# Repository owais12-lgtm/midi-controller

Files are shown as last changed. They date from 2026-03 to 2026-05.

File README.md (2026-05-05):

# midi-controller
A MIDI keyboard is basically just a controller. You can use it to trigger notes on a synth or plugin, you can assign the encoder to volume, LFO rate or anything else. So if you don't connect it to anything you won't get any sound.

tldr: its a smaller more weirder keyboard that can help you make music!

# features
- 6 rotary knobs for menu/Midi control
- 4 sliders
- 25 macro keys
- rp2040 based micro controller 
- choc switches
# Images

Screenshot from 2026-03-26 12-45-57
Screenshot from 2026-03-26 12-45-47
Screenshot from 2026-03-26 12-45-36

# CAD
Screenshot from 2026-03-26 12-46-45
Screenshot from 2026-03-26 12-46-54

https://www.tinkercad.com/things/4G5PN0rRYm5-midi-controller-v2

# BOM
| Name | Purpose | Quantity | Total Cost (USD) | Link | Distributor |
|---|---|---|---|---|---|
| switch | switch | 30 | $10.00 | [stackskb.com](https://stackskb.com/store/ttc-low-profile-brown-switches-tactile/) | stacks |
| rpi pico | mcu | 1 | $7.00 | [robu](https://www.google.com/search?client=firefox-b-d&q=rpi+pico+robu) | robu |
| pcb | pcb | 1 | $30.00 | [lioncircuits.com](https://www.lioncircuits.com/quote) | lion pcb |

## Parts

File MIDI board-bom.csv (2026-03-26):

Name | Purpose | Quantity | Total Cost (USD) | Link | Distributor
switch | switch | 30 | 10.00 | https://stackskb.com/store/ttc-low-profile-brown-switches-tactile/ | stacks
rpi pico | mcu | 1 | 7.00 | https://www.google.com/search?client=firefox-b-d&q=rpi+pico+robu | robu
pcb | pcb | 1 | 30.00 | https://www.lioncircuits.com/quote | lion pcb

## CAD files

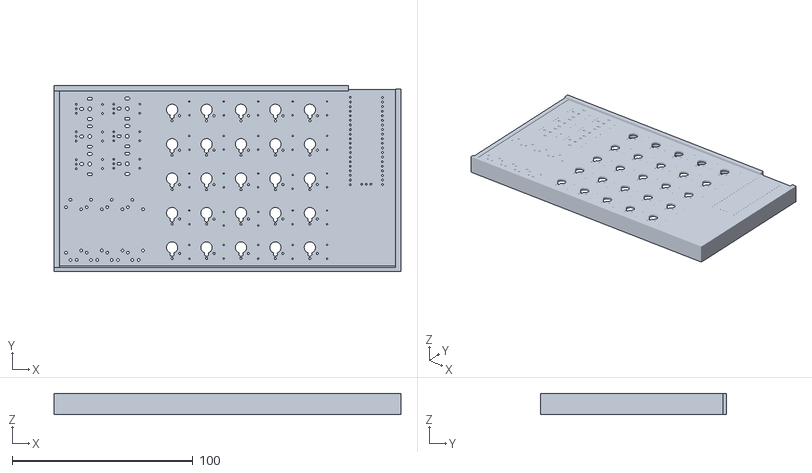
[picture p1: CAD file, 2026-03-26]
CAD/MIDI controller v2.stl
192.0 x 103.0 x 11.8

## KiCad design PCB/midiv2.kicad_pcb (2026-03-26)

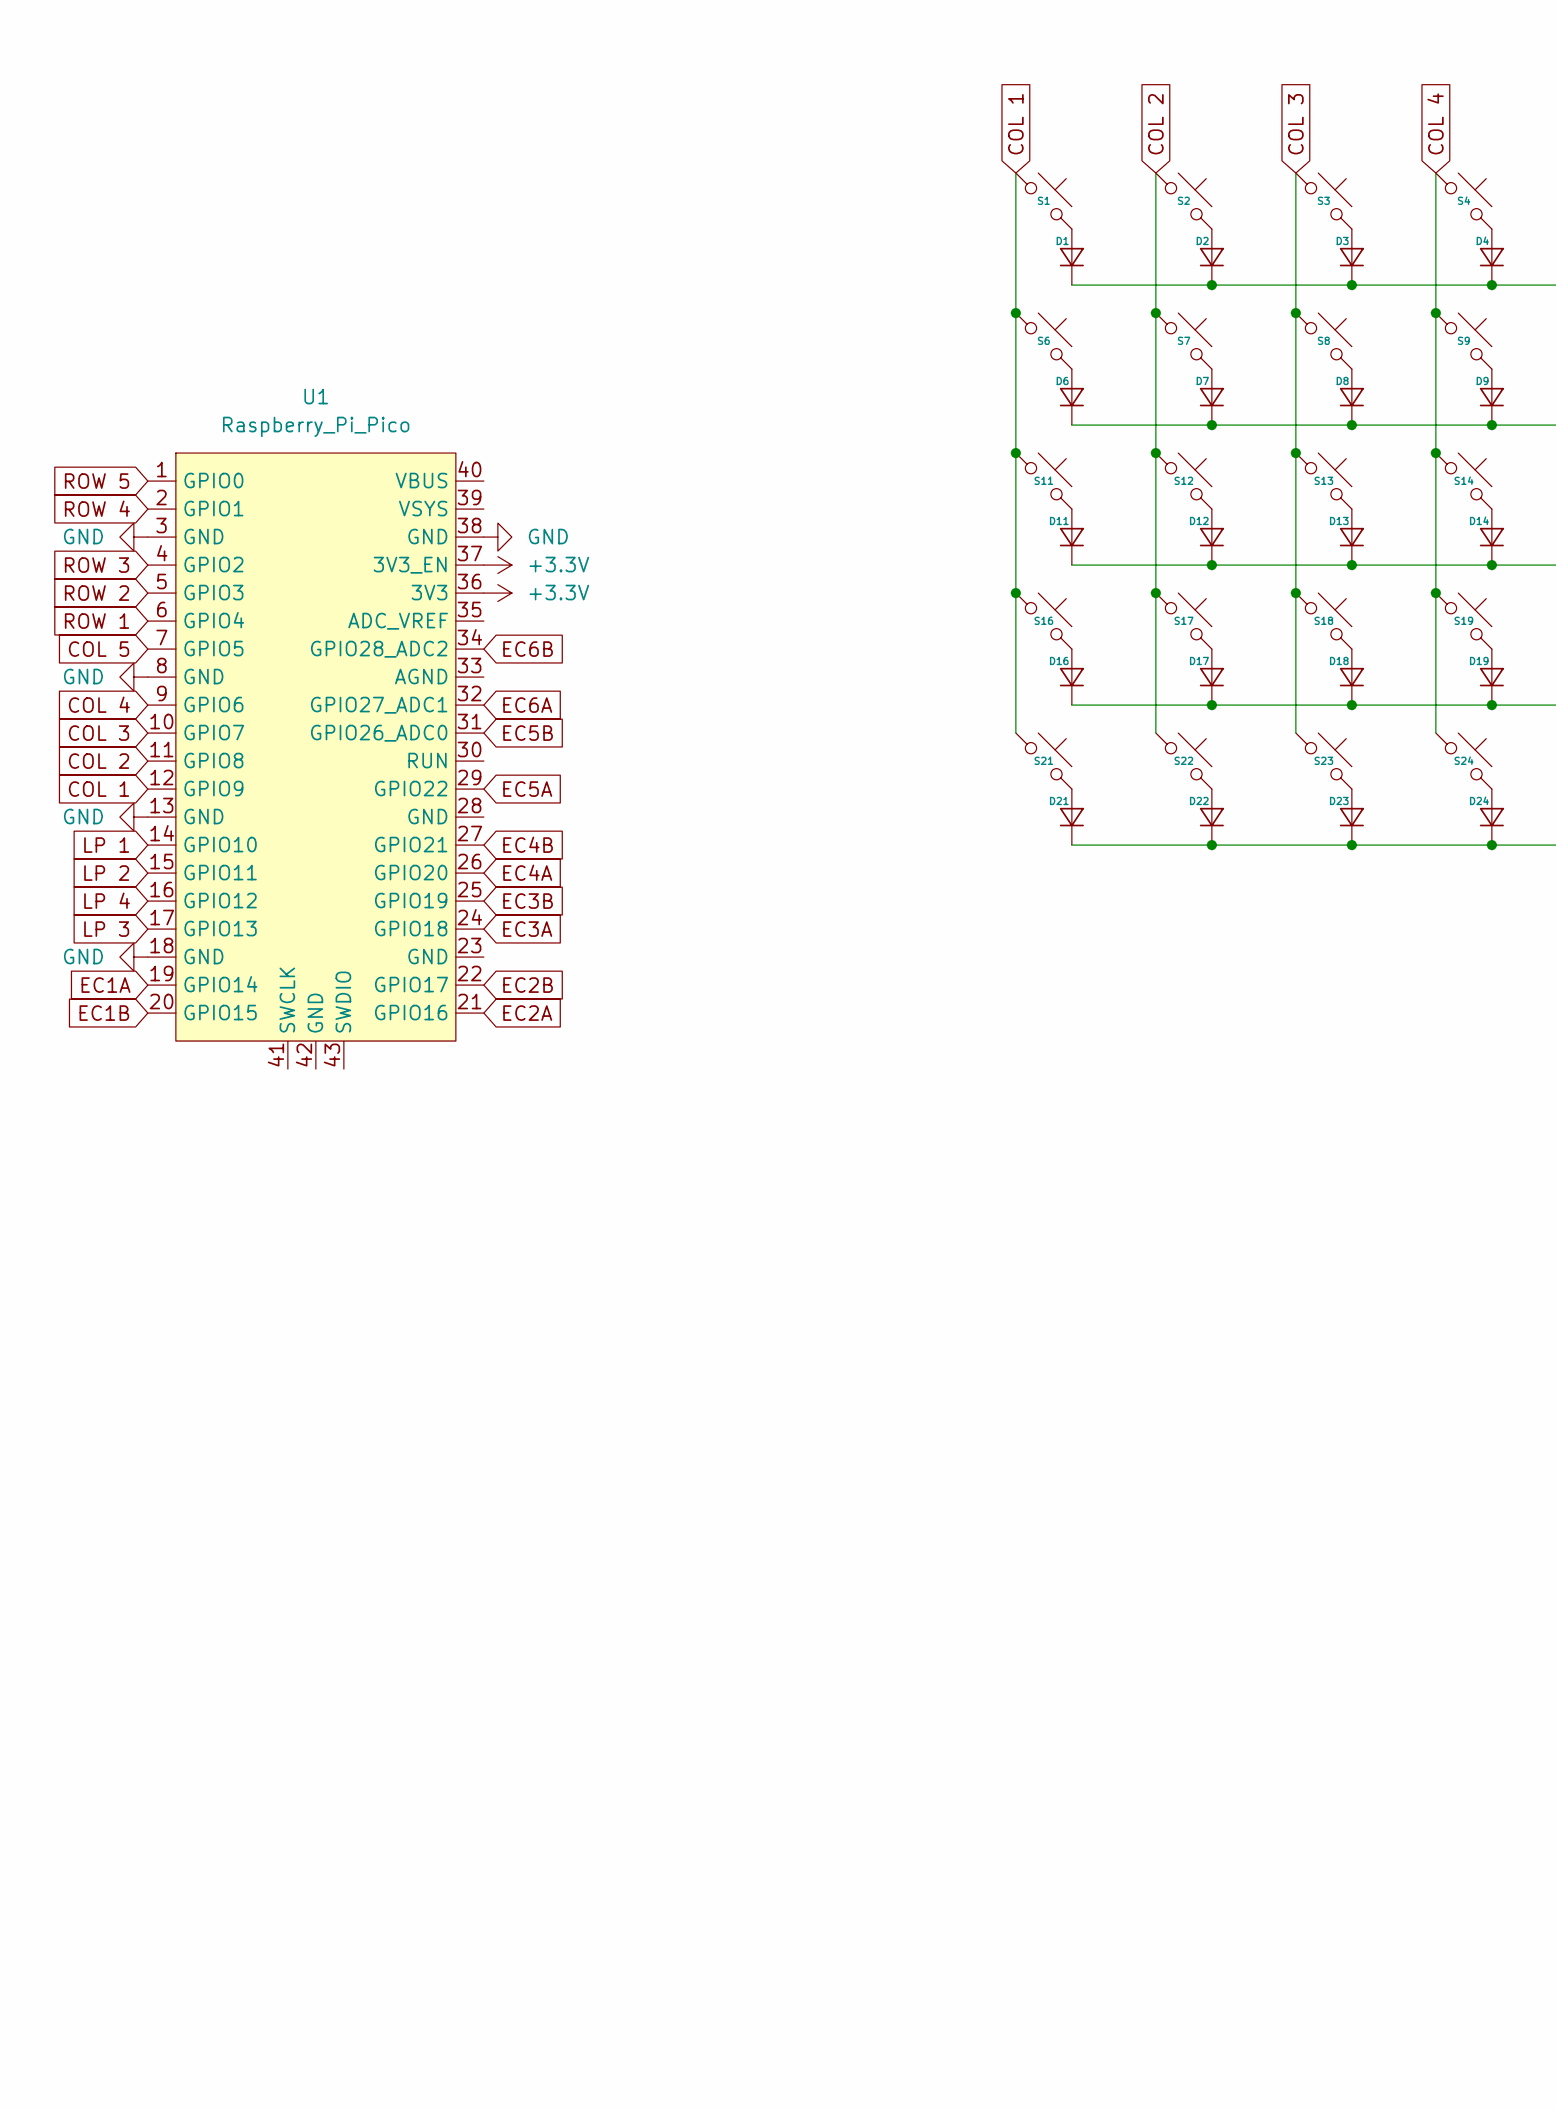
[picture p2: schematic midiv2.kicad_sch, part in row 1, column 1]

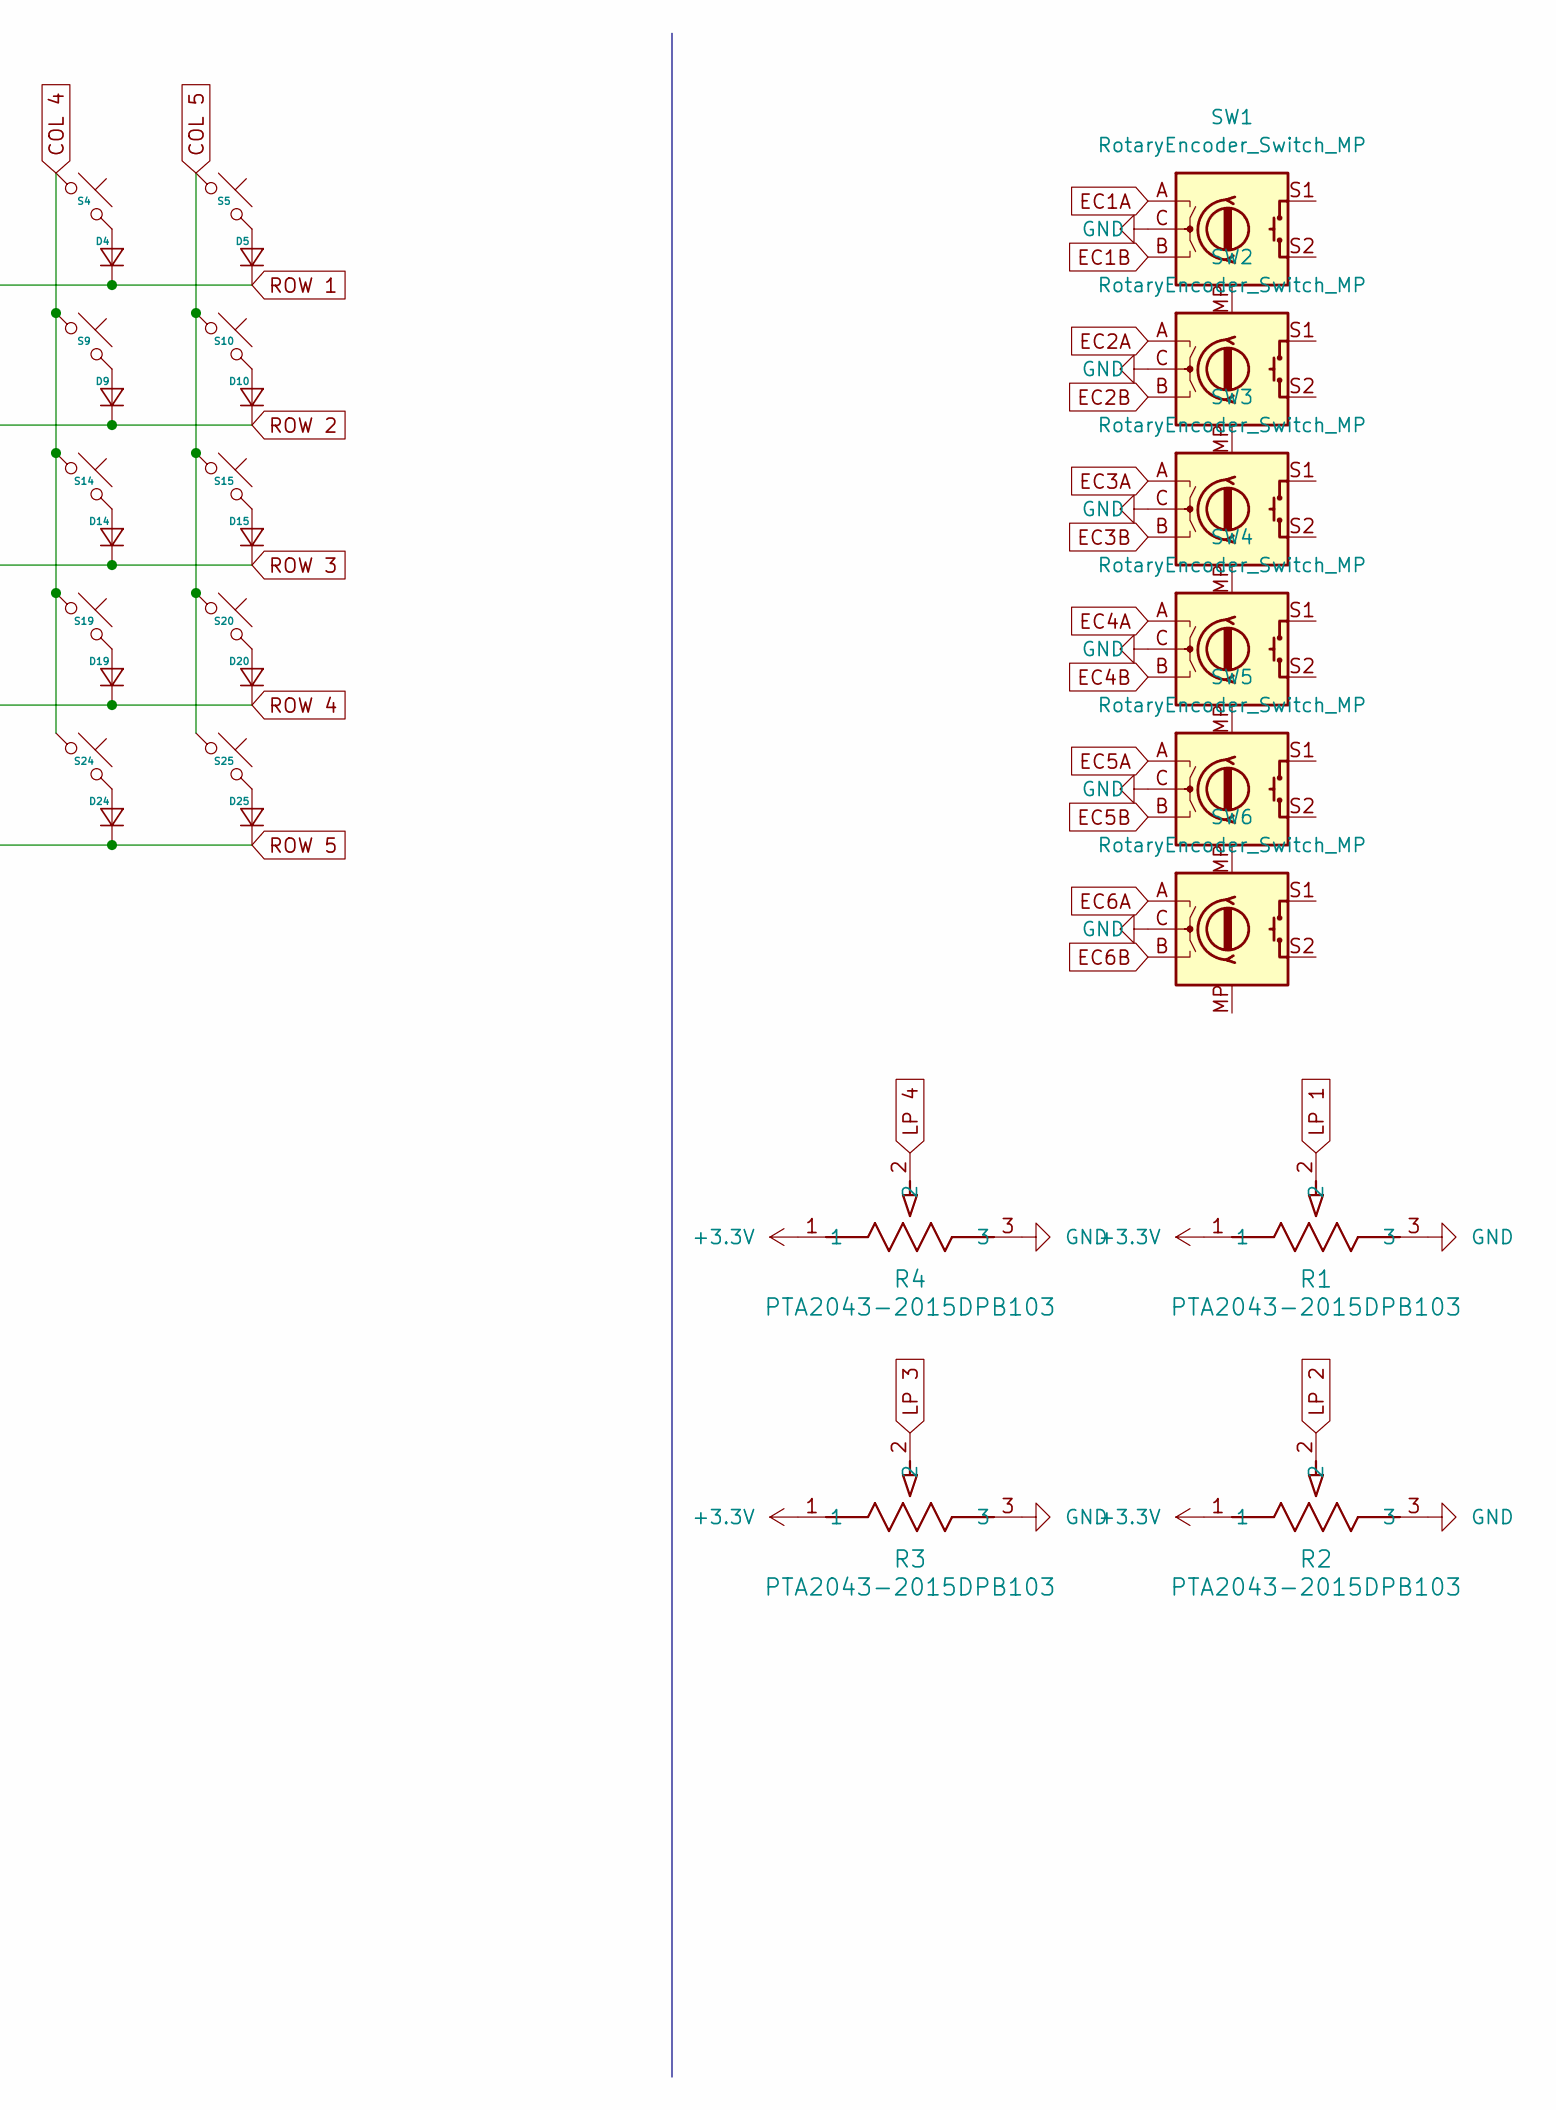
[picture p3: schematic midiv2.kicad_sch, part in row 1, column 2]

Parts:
D1, D2, D3, D4, D5, D6, D7, D8, D9, D10, D11, D12, D13, D14, D15, D16, D17, D18, D19, D20, D21, D22, D23, D24, D25: Diode_DO-35
R1, R2, R3, R4: PTA2043-2015DPB103; POT_PTA2043
S1, S2, S3, S4, S5, S6, S7, S8, S9, S10, S11, S12, S13, S14, S15, S16, S17, S18, S19, S20, S21, S22, S23, S24, S25: SW_MX_LowProfile_THT
SW1, SW2, SW3, SW4, SW5, SW6: RotaryEncoder_Switch_MP; RotaryEncoder_Alps_EC11E-Switch_Vertical_H20mm_MountingHoles
U1: Raspberry_Pi_Pico

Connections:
+3.3V: R1.1, R2.1, R3.1, R4.1, U1.36 (3V3), U1.37 (3V3_EN)
COL 1: S1.1, S6.1, S11.1, S16.1, S21.1, U1.12 (GPIO9)
COL 2: S2.1, S7.1, S12.1, S17.1, S22.1, U1.11 (GPIO8)
COL 3: S3.1, S8.1, S13.1, S18.1, S23.1, U1.10 (GPIO7)
COL 4: S4.1, S9.1, S14.1, S19.1, S24.1, U1.9 (GPIO6)
COL 5: S5.1, S10.1, S15.1, S20.1, S25.1, U1.7 (GPIO5)
EC1A: SW1.A, U1.19 (GPIO14)
EC1B: SW1.B, U1.20 (GPIO15)
EC2A: SW2.A, U1.21 (GPIO16)
EC2B: SW2.B, U1.22 (GPIO17)
EC3A: SW3.A, U1.24 (GPIO18)
EC3B: SW3.B, U1.25 (GPIO19)
EC4A: SW4.A, U1.26 (GPIO20)
EC4B: SW4.B, U1.27 (GPIO21)
EC5A: SW5.A, U1.29 (GPIO22)
EC5B: SW5.B, U1.31 (GPIO26_ADC0)
EC6A: SW6.A, U1.32 (GPIO27_ADC1)
EC6B: SW6.B, U1.34 (GPIO28_ADC2)
GND: R1.3, R2.3, R3.3, R4.3, SW1.C, SW2.C, SW3.C, SW4.C, SW5.C, SW6.C, U1.3 (GND), U1.8 (GND), U1.13 (GND), U1.18 (GND), U1.38 (GND)
LP 1: R1.2, U1.14 (GPIO10)
LP 2: R2.2, U1.15 (GPIO11)
LP 3: R3.2, U1.17 (GPIO13)
LP 4: R4.2, U1.16 (GPIO12)
unnamed: D1.2 (A), S1.2
unnamed: D2.2 (A), S2.2
unnamed: D3.2 (A), S3.2
unnamed: D4.2 (A), S4.2
unnamed: D5.2 (A), S5.2
unnamed: D6.2 (A), S6.2
unnamed: D7.2 (A), S7.2
unnamed: D8.2 (A), S8.2
unnamed: D9.2 (A), S9.2
unnamed: D10.2 (A), S10.2
unnamed: D11.2 (A), S11.2
unnamed: D12.2 (A), S12.2
unnamed: D13.2 (A), S13.2
unnamed: D14.2 (A), S14.2
unnamed: D15.2 (A), S15.2
unnamed: D16.2 (A), S16.2
unnamed: D17.2 (A), S17.2
unnamed: D18.2 (A), S18.2
unnamed: D19.2 (A), S19.2
unnamed: D20.2 (A), S20.2
unnamed: D21.2 (A), S21.2
unnamed: D22.2 (A), S22.2
unnamed: D23.2 (A), S23.2
unnamed: D24.2 (A), S24.2
unnamed: D25.2 (A), S25.2
ROW 1: D1.1 (K), D2.1 (K), D3.1 (K), D4.1 (K), D5.1 (K), U1.6 (GPIO4)
ROW 2: D6.1 (K), D7.1 (K), D8.1 (K), D9.1 (K), D10.1 (K), U1.5 (GPIO3)
ROW 3: D11.1 (K), D12.1 (K), D13.1 (K), D14.1 (K), D15.1 (K), U1.4 (GPIO2)
ROW 4: D16.1 (K), D17.1 (K), D18.1 (K), D19.1 (K), D20.1 (K), U1.2 (GPIO1)
ROW 5: D21.1 (K), D22.1 (K), D23.1 (K), D24.1 (K), D25.1 (K), U1.1 (GPIO0)

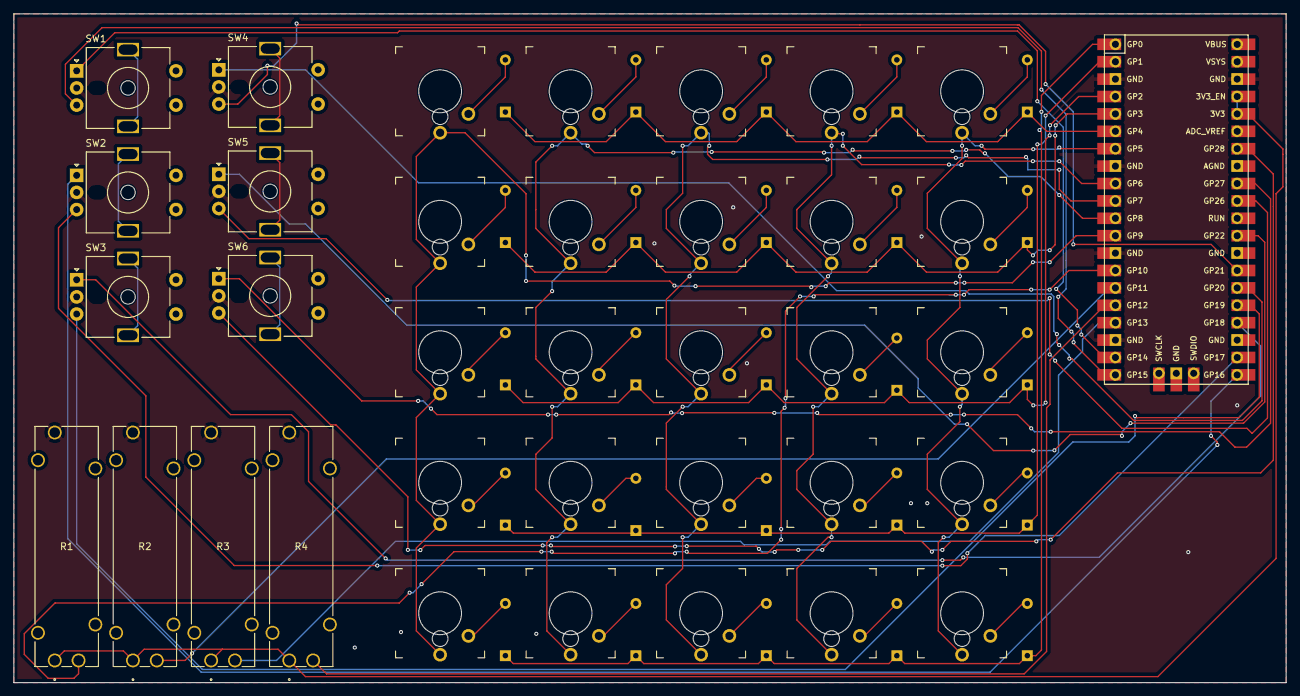
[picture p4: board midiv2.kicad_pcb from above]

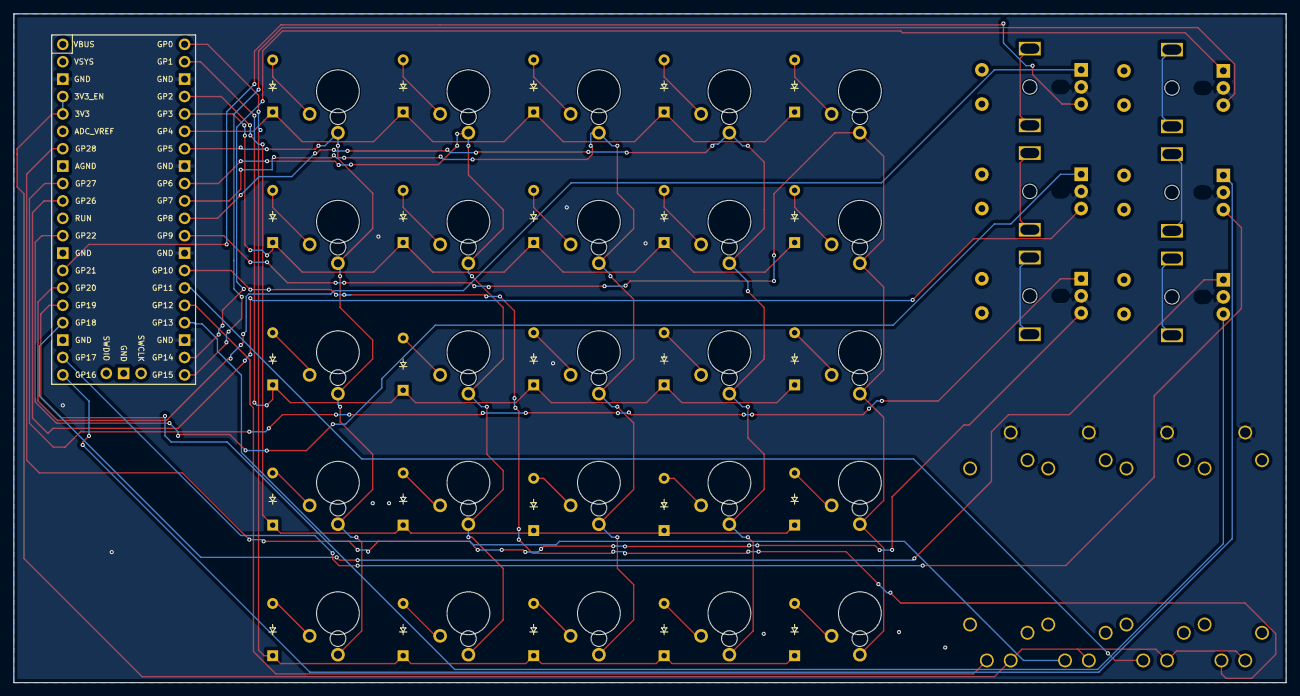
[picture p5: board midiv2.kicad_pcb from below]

Board: 2 copper layers, 185.7 x 97.6 mm, 61 parts (25 on the bottom side), 53 nets.

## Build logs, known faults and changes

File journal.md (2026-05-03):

# schemaitc, pcb and routing; 6 hrs

I made the sch for the midi controller, had some problems with footprints, i assigned wrong ones the first time then had to import a bunch for mx low profile switches

here are the footprints inported to pcb editor

I moved them to where i wanted them for the pcb

I had to route the whole pcb which was very time consuming and im pretty sure i have a record number of via's at 150


this is the final routed and ground planed pcb

# case design; 2 hrs


i made the case for my midi controller


# firmware; 2 hrs
I wrote some circuit python code for my midi firmware, the sliders now control volume for MIDI channels 1–4. the encoders go thru presets and the keys send note on/off msgs



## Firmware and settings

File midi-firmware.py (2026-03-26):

import board
import busio
import digitalio
import rotaryio
import analogio
import usb_midi
import adafruit_midi
import time
from adafruit_midi.note_on import NoteOn
from adafruit_midi.note_off import NoteOff
from adafruit_midi.control_change import ControlChange
from adafruit_midi.program_change import ProgramChange

midi = adafruit_midi.MIDI(
    midi_in=usb_midi.ports[0],
    midi_out=usb_midi.ports[1],
    out_channel=0,
    in_channel=0,
)

MIDI_CHANNEL = 0

ROW_PINS = [board.GP4, board.GP3, board.GP2, board.GP1, board.GP0]
COL_PINS = [board.GP9, board.GP8, board.GP7, board.GP6, board.GP5]

rows = []
for pin in ROW_PINS:
    p = digitalio.DigitalInOut(pin)
    p.direction = digitalio.Direction.OUTPUT
    p.value = True
    rows.append(p)

cols = []
for pin in COL_PINS:
    p = digitalio.DigitalInOut(pin)
    p.direction = digitalio.Direction.INPUT
    p.pull = digitalio.Pull.UP
    cols.append(p)

BASE_NOTE = 48

def key_note(row, col):
    return BASE_NOTE + row * 5 + col

VELOCITY = 100
key_state = [[False] * 5 for _ in range(5)]

def scan_matrix():
    for r, row_pin in enumerate(rows):
        row_pin.value = False
        for c, col_pin in enumerate(cols):
            pressed = not col_pin.value
            if pressed and not key_state[r][c]:
                note = key_note(r, c)
                midi.send(NoteOn(note, VELOCITY))
                key_state[r][c] = True
            elif not pressed and key_state[r][c]:
                note = key_note(r, c)
                midi.send(NoteOff(note, 0))
                key_state[r][c] = False
        row_pin.value = True

ENCODER_AB_PINS = [
    (board.GP14, board.GP15),
    (board.GP16, board.GP17),
    (board.GP18, board.GP19),
    (board.GP20, board.GP21),
    (board.GP22, board.GP23),
    (board.GP26, board.GP27),
]

encoders = []
for a, b in ENCODER_AB_PINS:
    encoders.append(rotaryio.IncrementalEncoder(a, b))

encoder_positions = [enc.position for enc in encoders]
encoder_programs = [0] * 6

def scan_encoders():
    for i, enc in enumerate(encoders):
        pos = enc.position
        delta = pos - encoder_positions[i]
        if delta != 0:
            encoder_programs[i] = max(0, min(127, encoder_programs[i] + delta))
            midi.send(ProgramChange(encoder_programs[i]))
            encoder_positions[i] = pos

SLIDER_PINS = [board.GP10, board.GP11, board.GP12, board.GP13]
SLIDER_CC = 7
SLIDER_CHANNELS = [0, 1, 2, 3]
SLIDER_DEADBAND = 200

sliders = [analogio.AnalogIn(pin) for pin in SLIDER_PINS]
slider_last = [None] * 4

def scan_sliders():
    for i, slider in enumerate(sliders):
        raw = slider.value
        cc_val = raw >> 9
        if slider_last[i] is None or abs(raw - slider_last[i]) > SLIDER_DEADBAND:
            midi.send(ControlChange(SLIDER_CC, cc_val), channel=SLIDER_CHANNELS[i])
            slider_last[i] = raw

print("MIDI Controller ready.")

while True:
    scan_matrix()
    scan_encoders()
    scan_sliders()
    time.sleep(0.001)
